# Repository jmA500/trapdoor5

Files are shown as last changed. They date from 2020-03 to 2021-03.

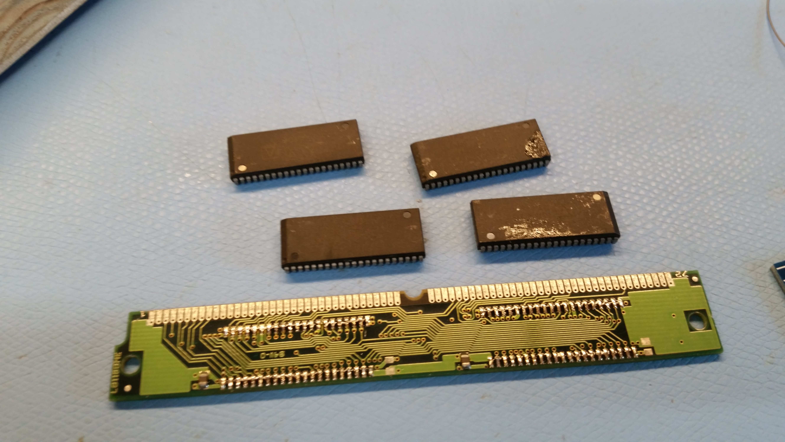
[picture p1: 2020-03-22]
doc/ps2-desoldered.jpg

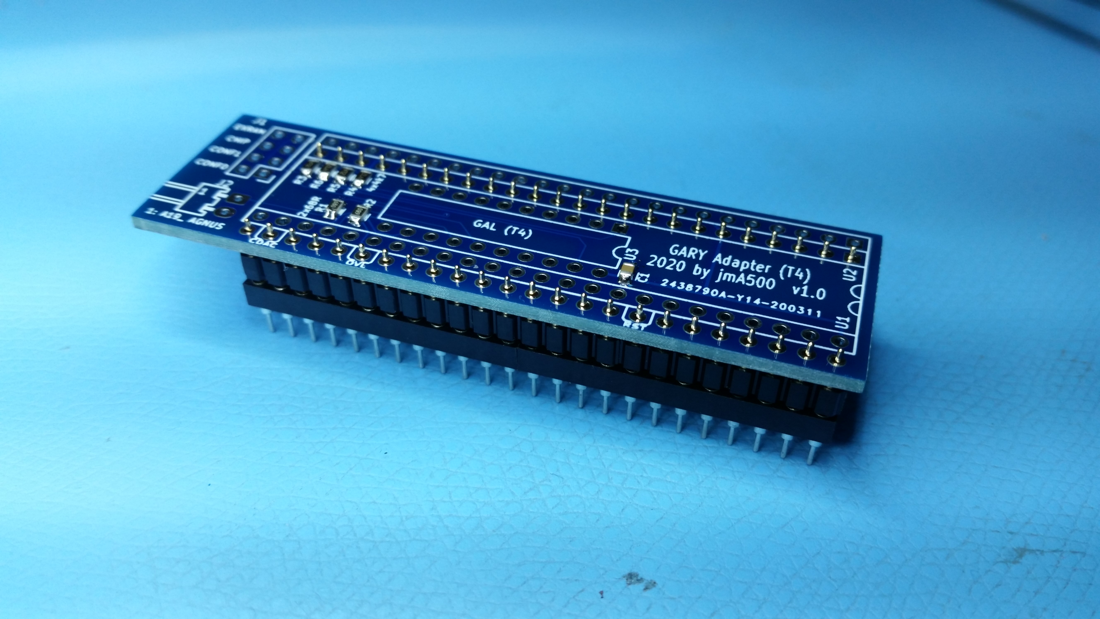
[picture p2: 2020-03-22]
doc/solder-pins.jpg

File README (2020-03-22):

This repository contains all the files to construct a Trapddor
expansion for the Amiga 500. There are some variants available. For
more information see the project website:

     https://www.jm27.de/for-commodore-amiga-500-1-8-mb-2mb-trapdoor-memory-expansion/

One variant uses a universal GARY Adapter (T3), the second one a
spcialized GARY adapter (T4). The T3 variant has as a main benefit
that the GARY adapter can be used with other original memory expansion
boards using a 74'139 to multiplex the CAS lines. The T4 version's
main feature is that there is no exra connection needed between the
GARY adapter and the Trapdoor board. 

Directories:

- doc: some documentation, needs to be extended

- pcb-trapdoor: kicad files for the pcb for the trapdoor assembly,
  both variants
- gal-trapdoor: Source and JED files for the GAL used on the trapdoor board
  CBR5SEL is needed for the T3 variant of the GARY adapter,
  CBR5EX is for the T4 variant
-pcb-gary-sel: the T3 GARY adater, kicad files
-pcb-gary-ext: the T4 GARY adapter, kicad files

- gal-gary: the corresponding GAL files
  GARY-T3: for the T3 variant
  GARY-T4: for the T4 variant

The PLD files can be compiled with WinCUPL available from Microchip. I
would be grateful fo a suggestion of a free alternative.

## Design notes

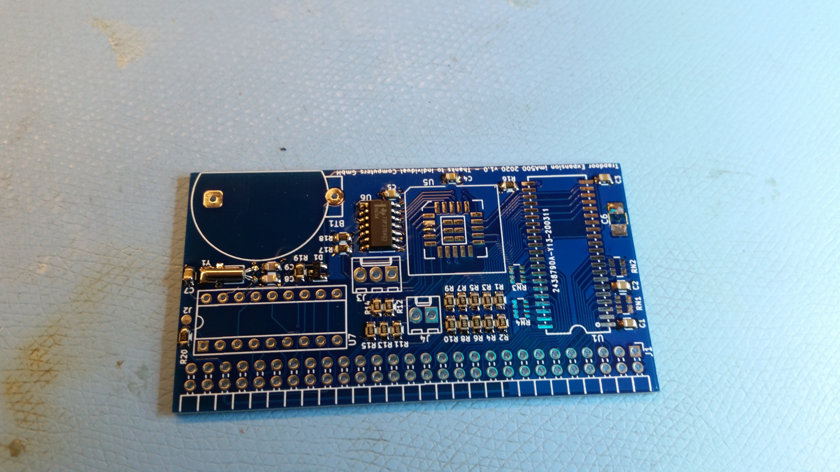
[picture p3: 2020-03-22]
doc/pcb-trapdoor.jpg

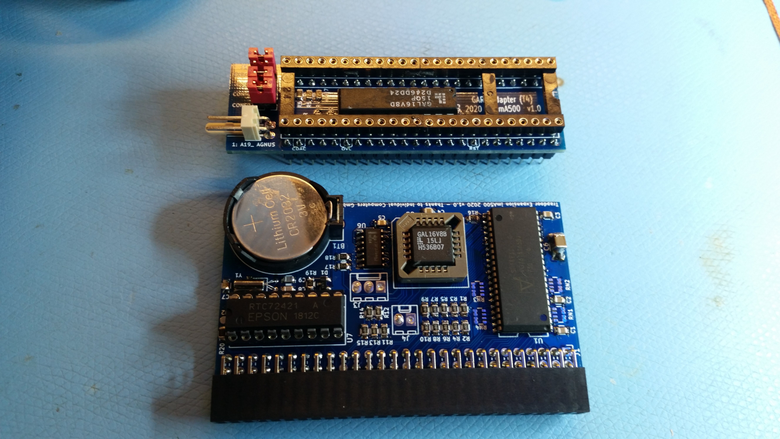
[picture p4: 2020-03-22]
doc/finished.jpg

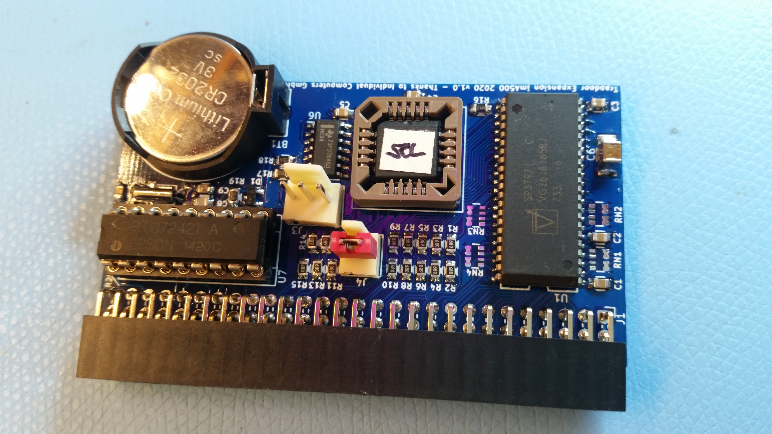
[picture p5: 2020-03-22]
doc/trapdoor-fertig.jpg

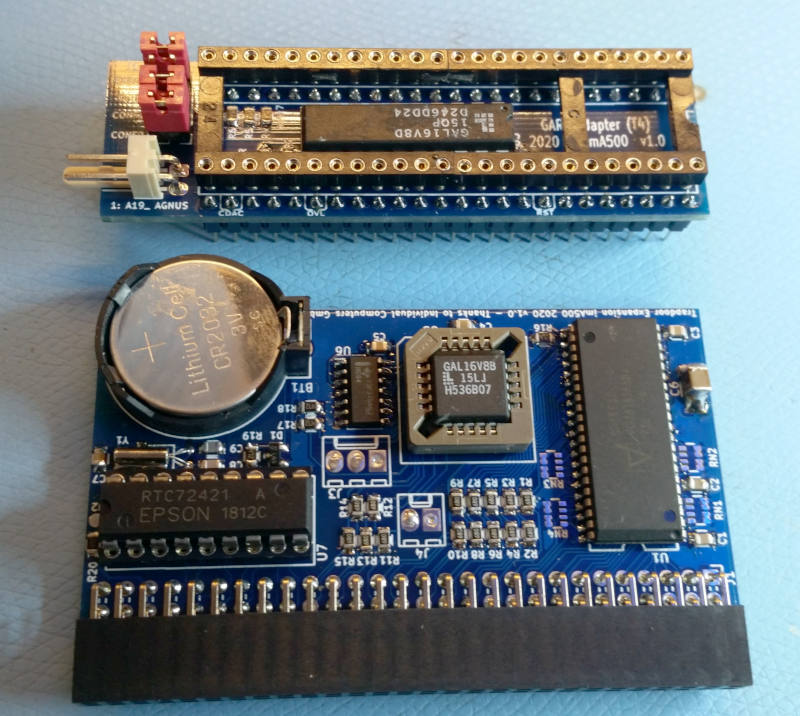
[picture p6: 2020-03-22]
doc/finished-small.jpg

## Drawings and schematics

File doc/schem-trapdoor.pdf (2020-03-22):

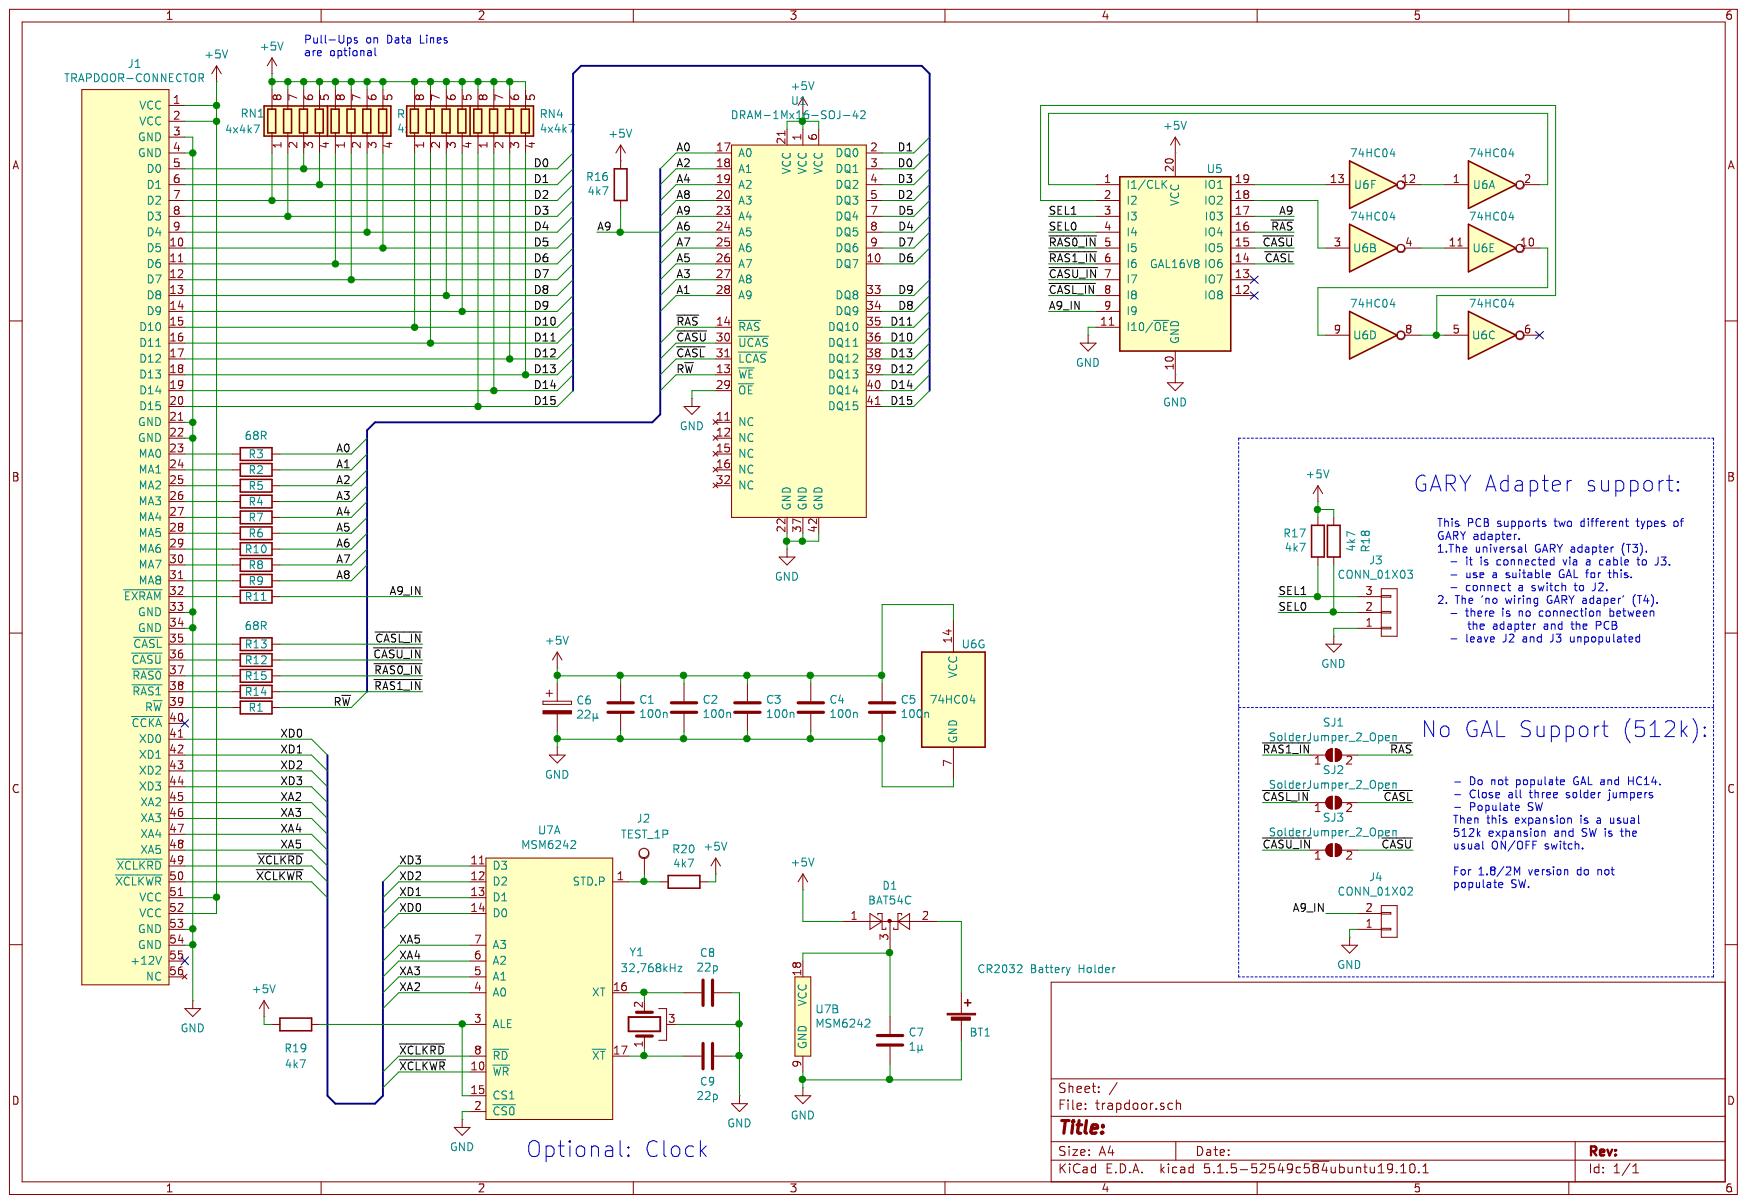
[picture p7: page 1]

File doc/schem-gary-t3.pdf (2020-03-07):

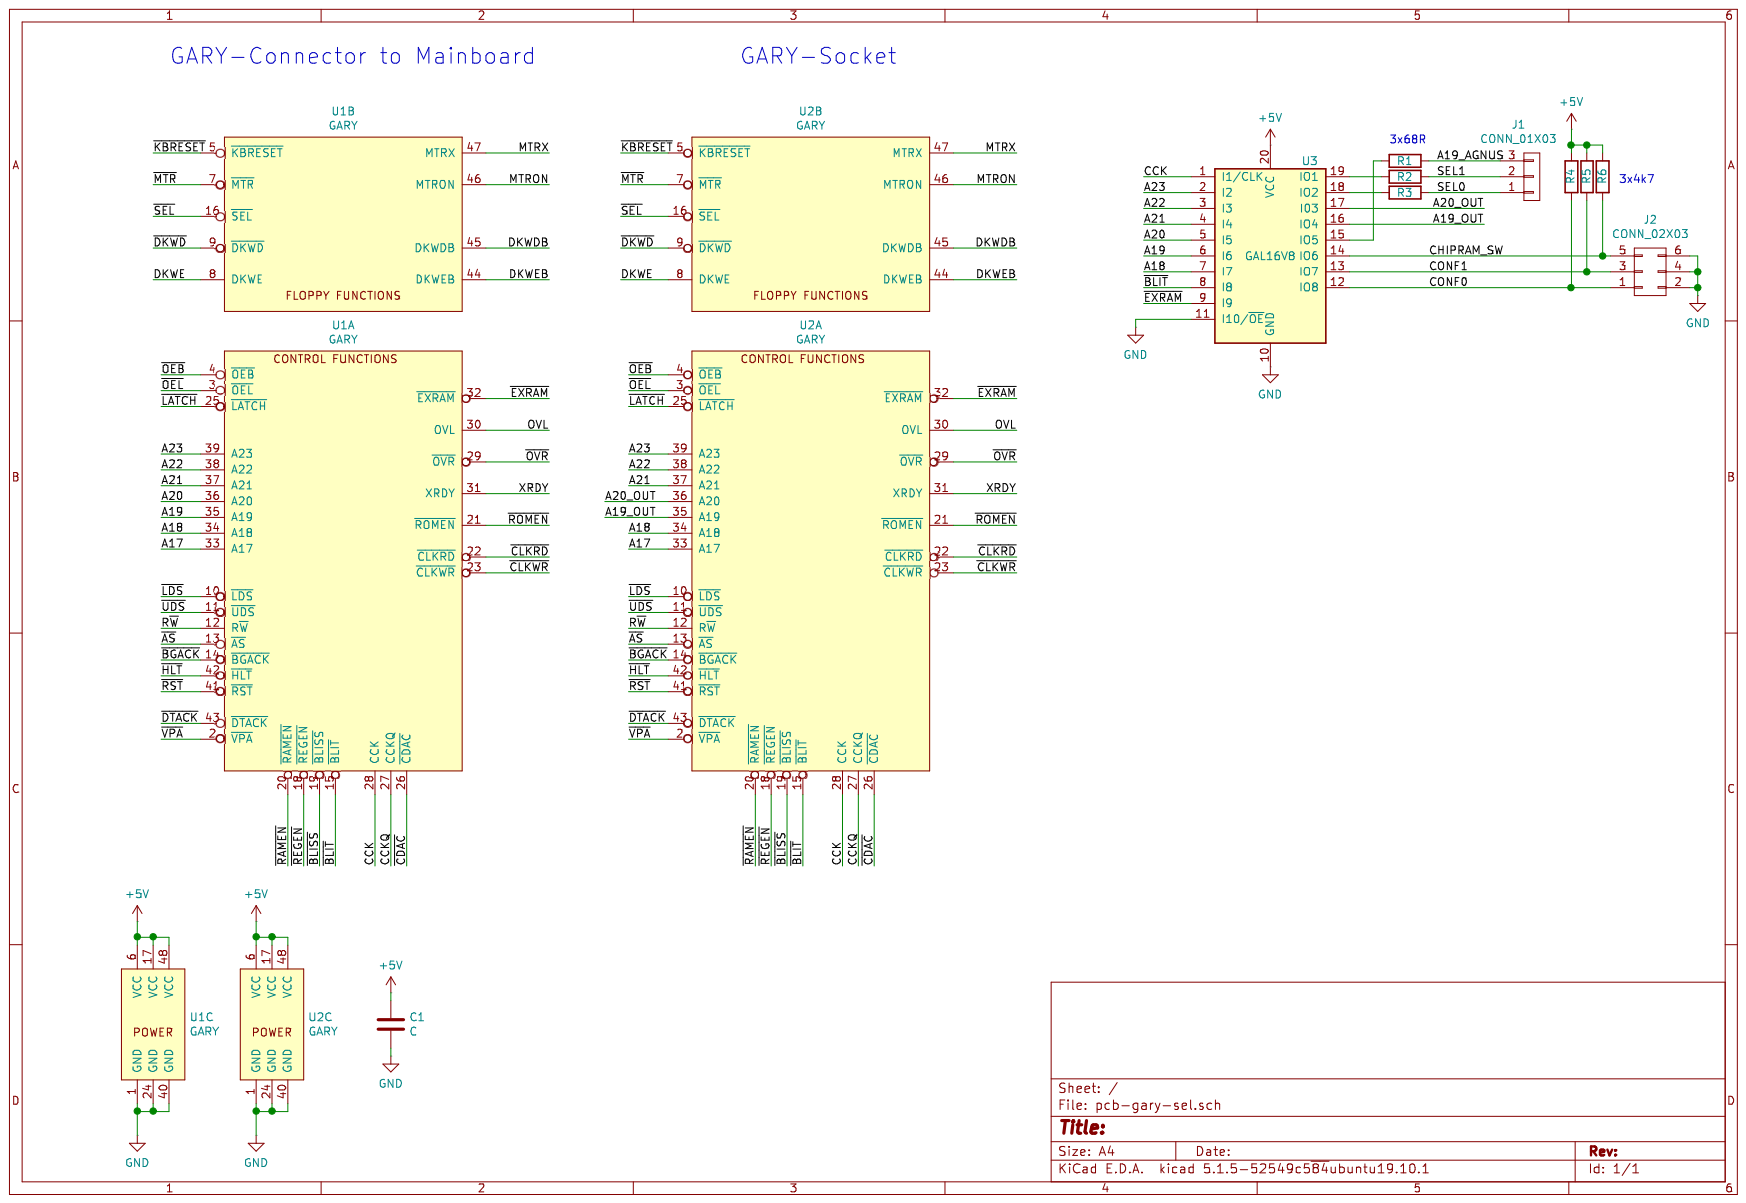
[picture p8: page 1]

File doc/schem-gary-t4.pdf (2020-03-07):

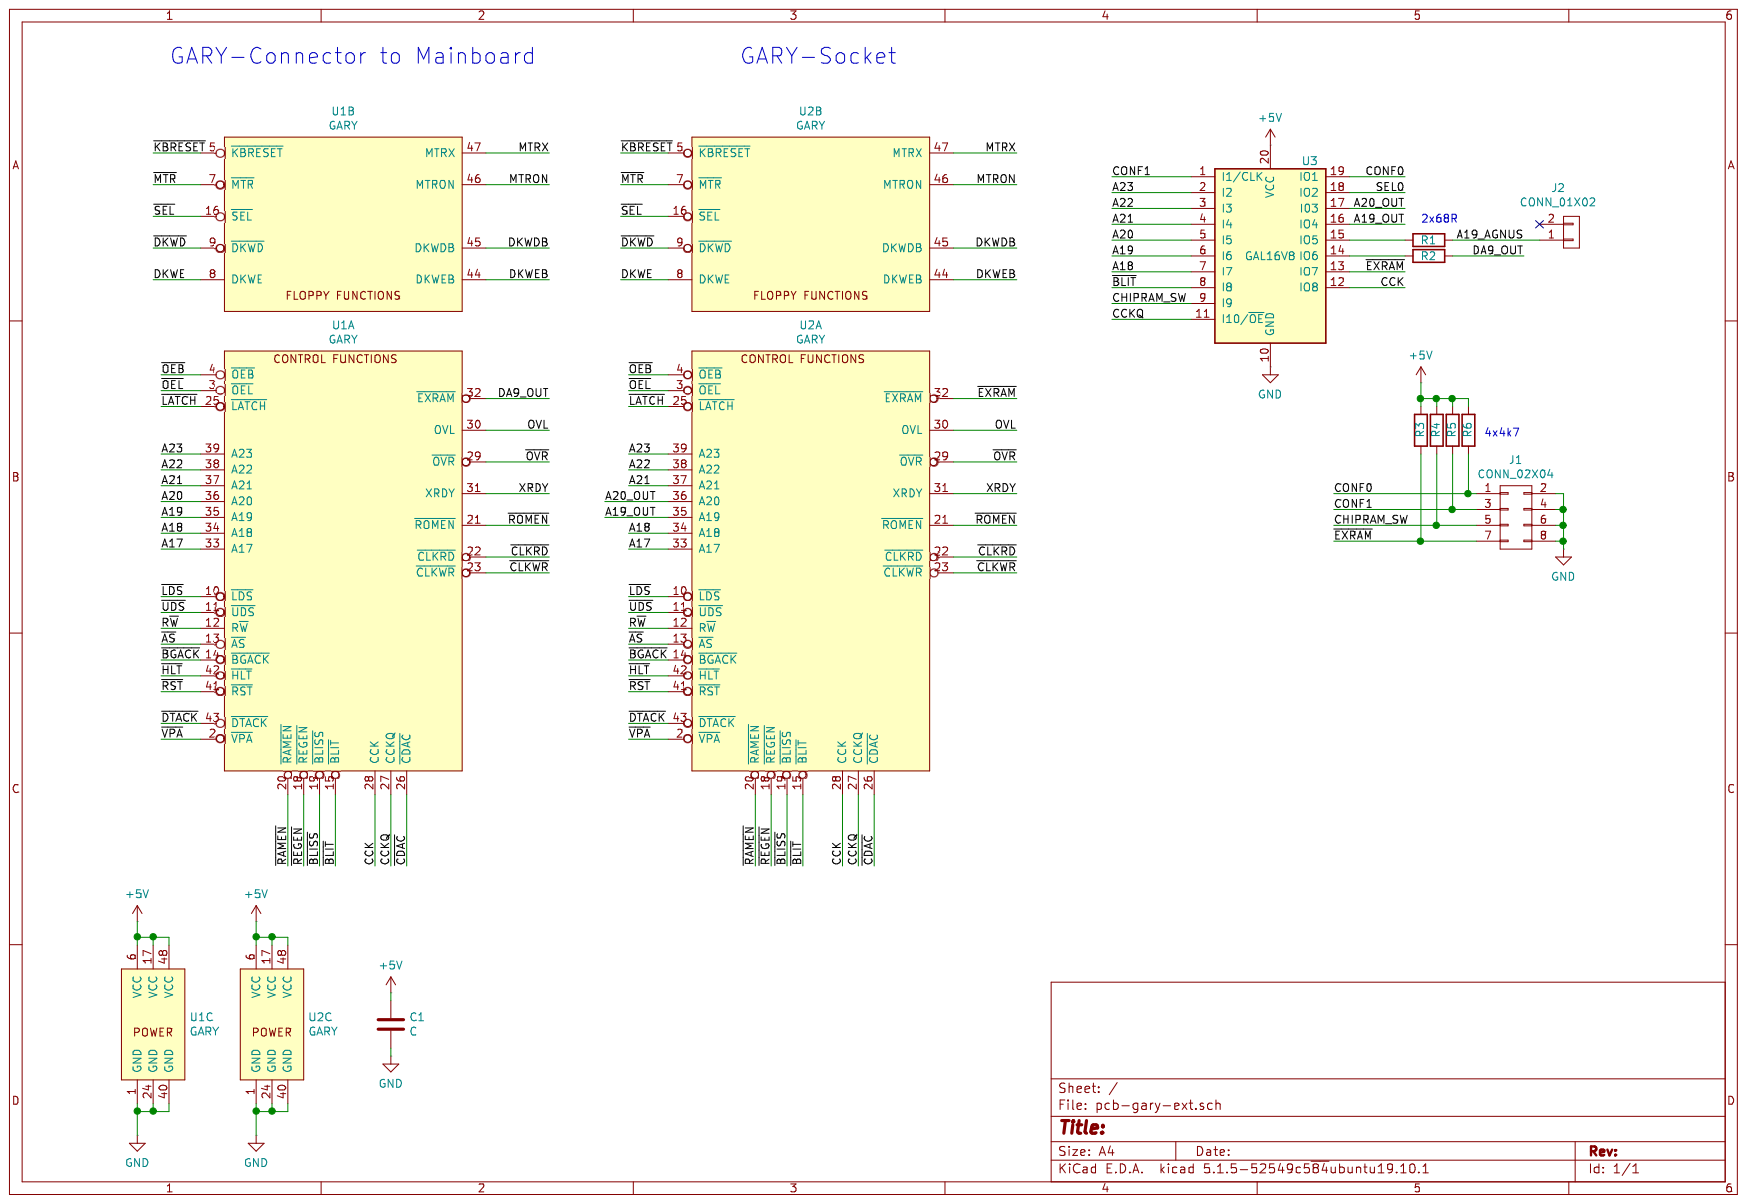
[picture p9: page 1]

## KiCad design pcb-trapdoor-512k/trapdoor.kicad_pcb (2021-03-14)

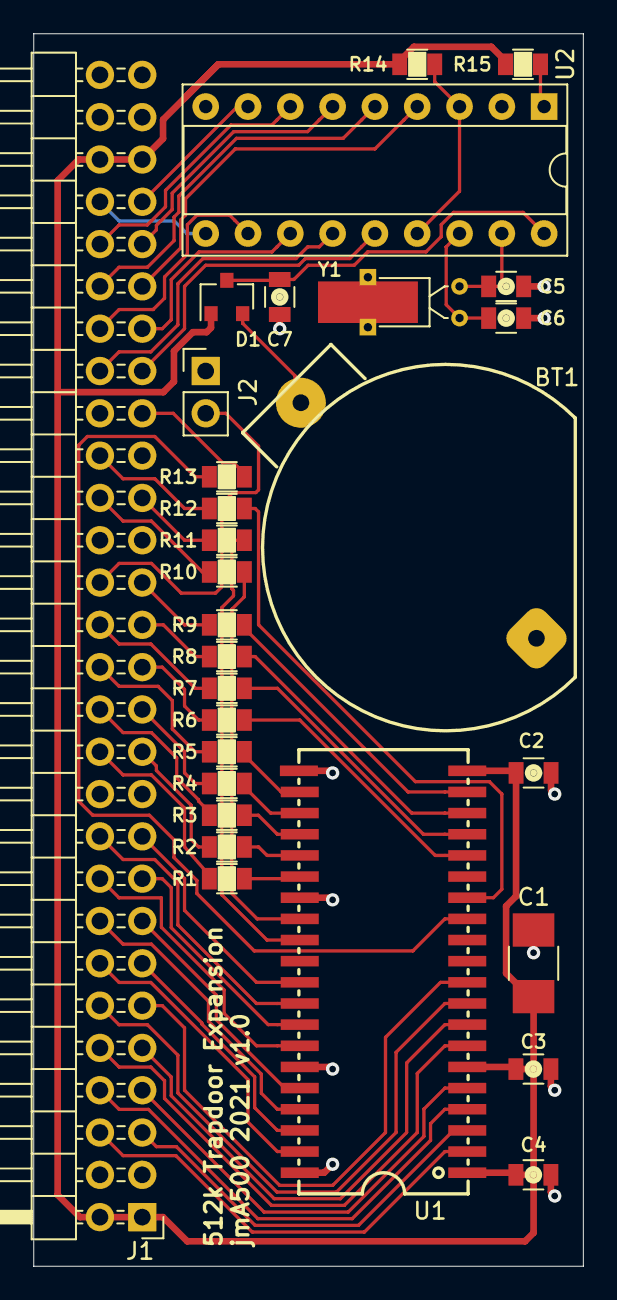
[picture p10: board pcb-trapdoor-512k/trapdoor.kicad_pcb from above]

Board: 2 copper layers, 33.0 x 74.0 mm, 29 parts (0 on the bottom side), 61 nets.

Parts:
BT1: CR2032 Battery Holder; BAT-CR2023-45
C1: 22µ; C_1210_HandSoldering
C2, C3, C4: 100n; C_0805
C5, C6: 22p; C_0805
C7: 1µ; C_0805
D1: BAT54C; SOT-23
J1: TRAPDOOR-CONNECTOR; Pin_Header_Angled_2x28_Pitch2.54mm
J2: CONN_01X02; Pin_Header_Straight_1x02_Pitch2.54mm
R1, R2, R3, R4, R5, R6, R7, R8, R9, R10, R11, R12, R13: 68R; R_0805
R14, R15: 4k7; R_0805
U1: DRAM-256kx16-SOJ; SOJ-40
U2: MSM6242; DIP-18_W7.62mm_Socket
Y1: 32,768kHz; Crystal_DS26_d2.0mm_l6.0mm_Horizontal_1EP_style2

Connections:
+5V: C1.1, C2.2, C3.2, C4.2, D1.1, J1.1, J1.2, J1.51, J1.52, R14.2, R15.1, U1.1, U1.6, U1.20
/A0: R2.1, U1.25
/A1: R1.1, U1.26
/A2: R4.1, U1.23
/A3: R3.1, U1.24
/A4: R6.1, U1.16
/A5: R5.1, U1.22
/A6: R8.1, U1.18
/A7: R7.1, U1.17
/A8: R9.1, U1.19
/D0: J1.5, U1.3
/D1: J1.6, U1.2
/D2: J1.7, U1.5
/D3: J1.8, U1.4
/D4: J1.9, U1.8
/D5: J1.10, U1.7
/D6: J1.11, U1.10
/D7: J1.12, U1.9
/D8: J1.13, U1.38
/D9: J1.14, U1.39
/D10: J1.15, U1.36
/D11: J1.16, U1.37
/D12: J1.17, U1.33
/D13: J1.18, U1.34
/D14: J1.19, U1.31
/D15: J1.20, U1.32
/R~W: R13.1, U1.13
/XA2: J1.45, U2.4
/XA3: J1.46, U2.5
/XA4: J1.47, U2.6
/XA5: J1.48, U2.7
/XD0: J1.41, U2.14
/XD1: J1.42, U2.13
/XD2: J1.43, U2.12
/XD3: J1.44, U2.11
/~CASL: R11.1, U1.29
/~CASU: R10.1, U1.28
/~EXRAM: J1.32, J2.2
/~RAS: R12.1, U1.14
/~XCLKRD: J1.49, U2.8
/~XCLKWR: J1.50, U2.10
GND: BT1.2, C1.2, C2.1, C3.1, C4.1, C5.1, C6.1, C7.1, J1.3, J1.4, J1.21, J1.22, J1.33, J1.34, J1.53, J1.54, J2.1, U1.21, U1.27, U1.35, U1.40, U2.2, U2.9, Y1.3
unnamed: BT1.1, D1.2
unnamed: C5.2, U2.17, Y1.1
unnamed: C6.2, U2.16, Y1.2
unnamed: C7.2, D1.3, U2.18
unnamed: J1.23, R2.2
unnamed: J1.24, R1.2
unnamed: J1.25, R4.2
unnamed: J1.26, R3.2
unnamed: J1.27, R6.2
unnamed: J1.28, R5.2
unnamed: J1.29, R8.2
unnamed: J1.30, R7.2
unnamed: J1.31, R9.2
unnamed: J1.35, R11.2
unnamed: J1.36, R10.2
unnamed: J1.38, R12.2
unnamed: J1.39, R13.2
unnamed: R14.1, U2.3, U2.15
unnamed: R15.2, U2.1

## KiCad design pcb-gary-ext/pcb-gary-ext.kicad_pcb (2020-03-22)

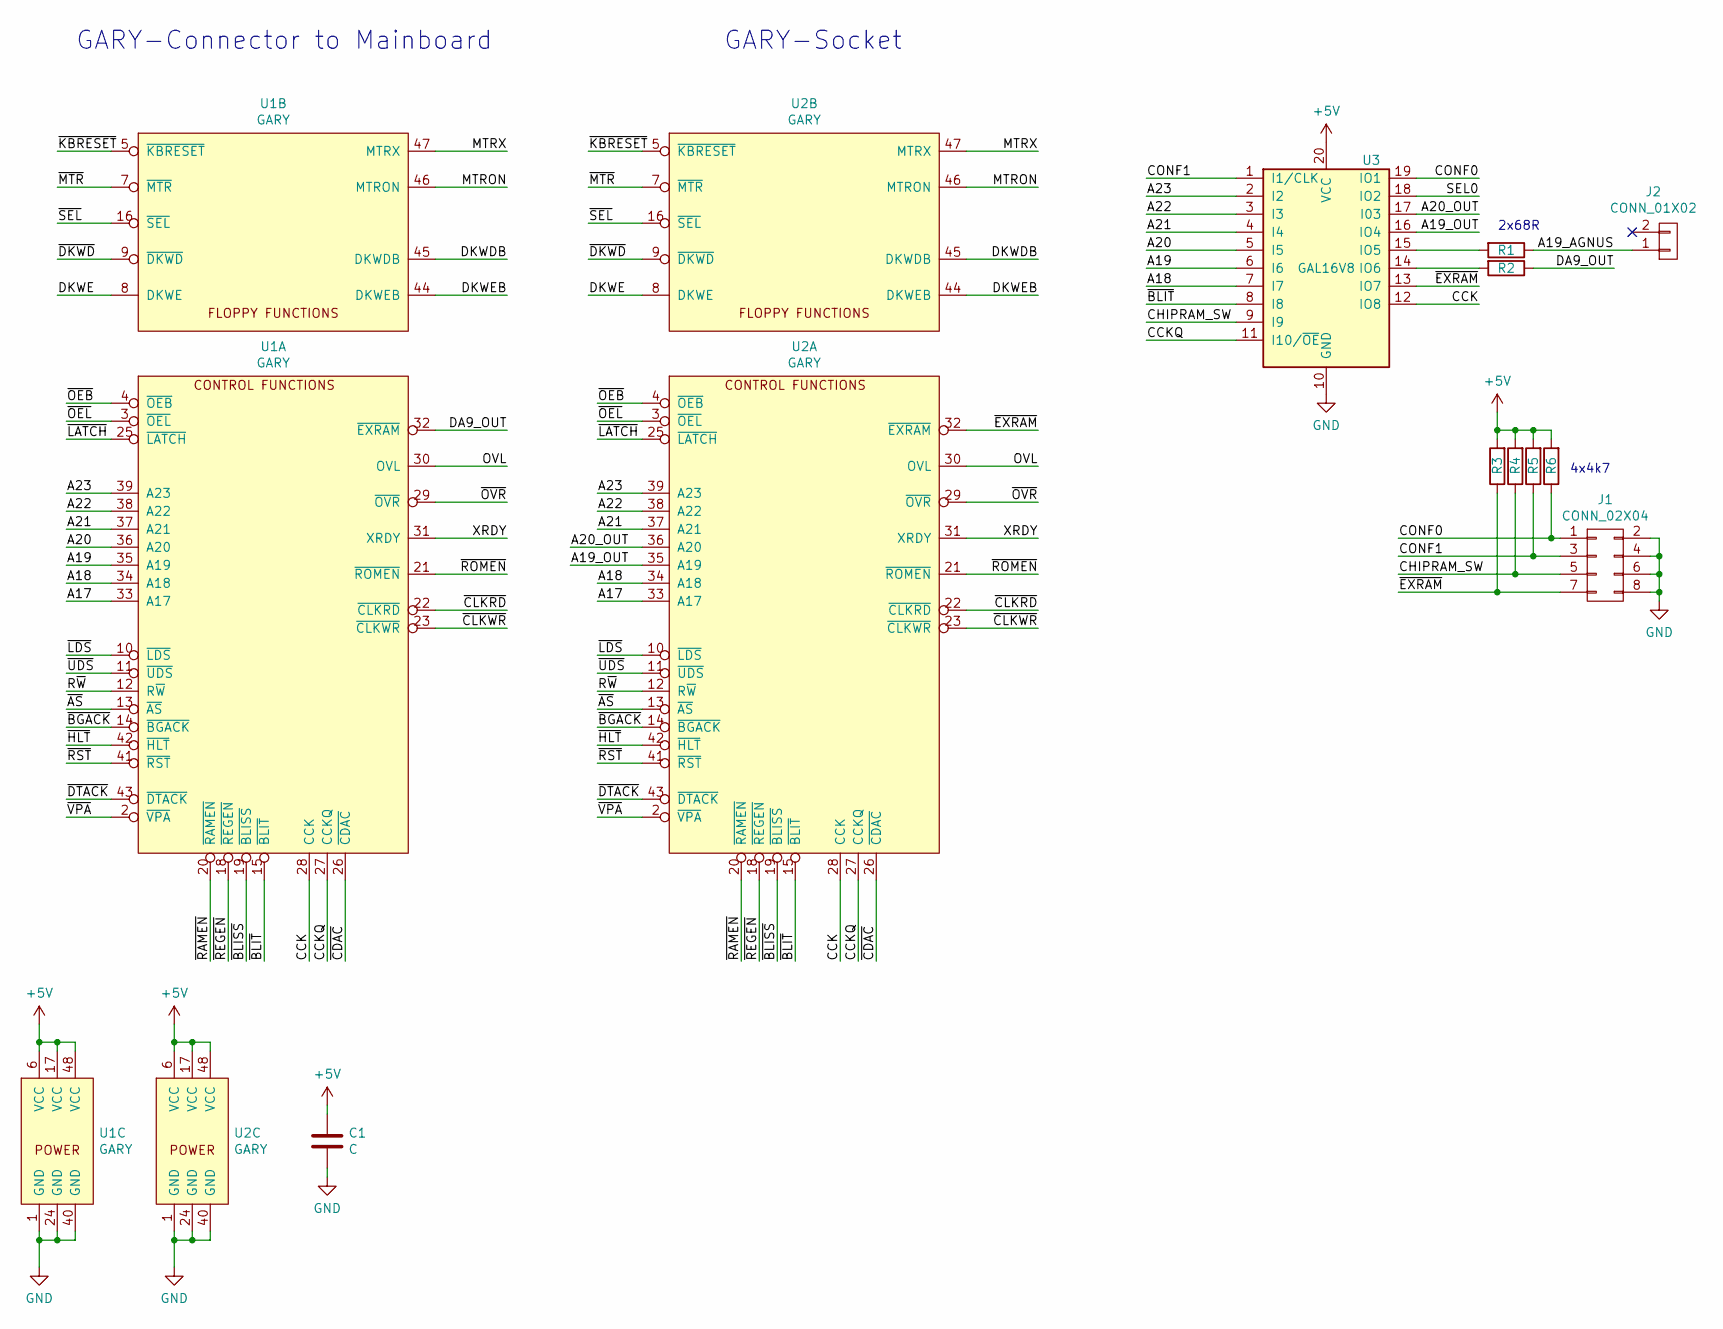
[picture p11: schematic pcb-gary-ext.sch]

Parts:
C1: C; C_0805
J1: CONN_02X04; Pin_Header_Straight_2x04_Pitch2.54mm
J2: CONN_01X02; MOLEX-KK-Angled-2
R1, R2: 68R; R_0805
R3, R4, R5, R6: 4k7; R_0805
U1, U2: GARY
U3: GAL16V8; DIP-20_W7.62mm

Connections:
+5V: C1.1, R3.2, R4.2, R5.2, R6.2, U1.6 (VCC), U1.17 (VCC), U1.48 (VCC), U2.6 (VCC), U2.17 (VCC), U2.48 (VCC), U3.20 (VCC)
/A17: U1.33 (A17), U2.33 (A17)
/A18: U1.34 (A18), U2.34 (A18), U3.7 (I7)
/A19: U1.35 (A19), U3.6 (I6)
/A19_AGNUS: J2.1, R1.1
/A19_OUT: U2.35 (A19), U3.16 (IO4)
/A20: U1.36 (A20), U3.5 (I5)
/A20_OUT: U2.36 (A20), U3.17 (I03)
/A21: U1.37 (A21), U2.37 (A21), U3.4 (I4)
/A22: U1.38 (A22), U2.38 (A22), U3.3 (I3)
/A23: U1.39 (A23), U2.39 (A23), U3.2 (I2)
/CCK: U1.28 (CCK), U2.28 (CCK), U3.12 (IO8)
/CCKQ: U1.27 (CCKQ), U2.27 (CCKQ), U3.11 (I10/~OE~)
/CHIPRAM_SW: J1.5, R4.1, U3.9 (I9)
/CONF0: J1.1, R6.1, U3.19 (IO1)
/CONF1: J1.3, R5.1, U3.1 (I1/CLK)
/DA9_OUT: R2.1, U1.32 (~EXRAM)
/DKWDB: U1.45 (DKWDB), U2.45 (DKWDB)
/DKWE: U1.8 (DKWE), U2.8 (DKWE)
/DKWEB: U1.44 (DKWEB), U2.44 (DKWEB)
/MTRON: U1.46 (MTRON), U2.46 (MTRON)
/MTRX: U1.47 (MTRX), U2.47 (MTRX)
/OVL: U1.30 (OVL), U2.30 (OVL)
/R~W: U1.12 (R~W), U2.12 (R~W)
/XRDY: U1.31 (XRDY), U2.31 (XRDY)
/~AS: U1.13 (~AS), U2.13 (~AS)
/~BGACK: U1.14 (~BGACK), U2.14 (~BGACK)
/~BLISS: U1.19 (~BLISS), U2.19 (~BLISS)
/~BLIT: U1.15 (~BLIT), U2.15 (~BLIT), U3.8 (I8)
/~CDAC: U1.26 (~CDAC), U2.26 (~CDAC)
/~CLKRD: U1.22 (~CLKRD), U2.22 (~CLKRD)
/~CLKWR: U1.23 (~CLKWR), U2.23 (~CLKWR)
/~DKWD: U1.9 (~DKWD), U2.9 (~DKWD)
/~DTACK: U1.43 (~DTACK), U2.43 (~DTACK)
/~EXRAM: J1.7, R3.1, U2.32 (~EXRAM), U3.13 (IO7)
/~HLT: U1.42 (~HLT), U2.42 (~HLT)
/~KBRESET: U1.5 (~KBRESET), U2.5 (~KBRESET)
/~LATCH: U1.25 (~LATCH), U2.25 (~LATCH)
/~LDS: U1.10 (~LDS), U2.10 (~LDS)
/~MTR: U1.7 (~MTR), U2.7 (~MTR)
/~OEB: U1.4 (~OEB), U2.4 (~OEB)
/~OEL: U1.3 (~OEL), U2.3 (~OEL)
/~OVR: U1.29 (~OVR), U2.29 (~OVR)
/~RAMEN: U1.20 (~RAMEN), U2.20 (~RAMEN)
/~REGEN: U1.18 (~REGEN), U2.18 (~REGEN)
/~ROMEN: U1.21 (~ROMEN), U2.21 (~ROMEN)
/~RST: U1.41 (~RST), U2.41 (~RST)
/~SEL: U1.16 (~SEL), U2.16 (~SEL)
/~UDS: U1.11 (~UDS), U2.11 (~UDS)
/~VPA: U1.2 (~VPA), U2.2 (~VPA)
GND: C1.2, J1.2, J1.4, J1.6, J1.8, U1.1 (GND), U1.24 (GND), U1.40 (GND), U2.1 (GND), U2.24 (GND), U2.40 (GND), U3.10 (GND)
unnamed: R1.2, U3.15 (IO5)
unnamed: R2.2, U3.14 (IO6)

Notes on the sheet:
GARY-Connector to Mainboard
GARY-Socket
2x68R
4x4k7

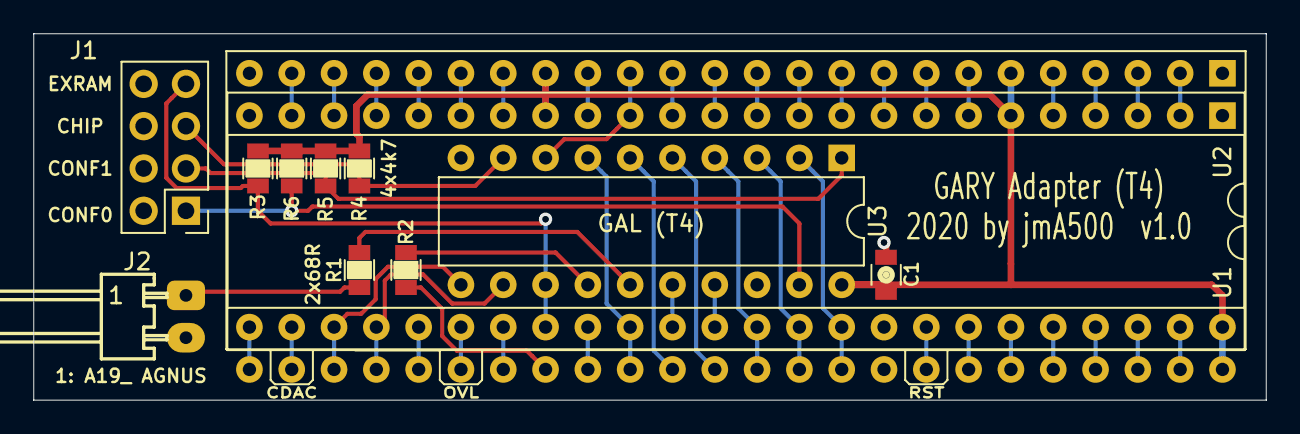
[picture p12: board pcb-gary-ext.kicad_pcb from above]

Board: 2 copper layers, 74.0 x 22.0 mm, 12 parts (0 on the bottom side), 53 nets.

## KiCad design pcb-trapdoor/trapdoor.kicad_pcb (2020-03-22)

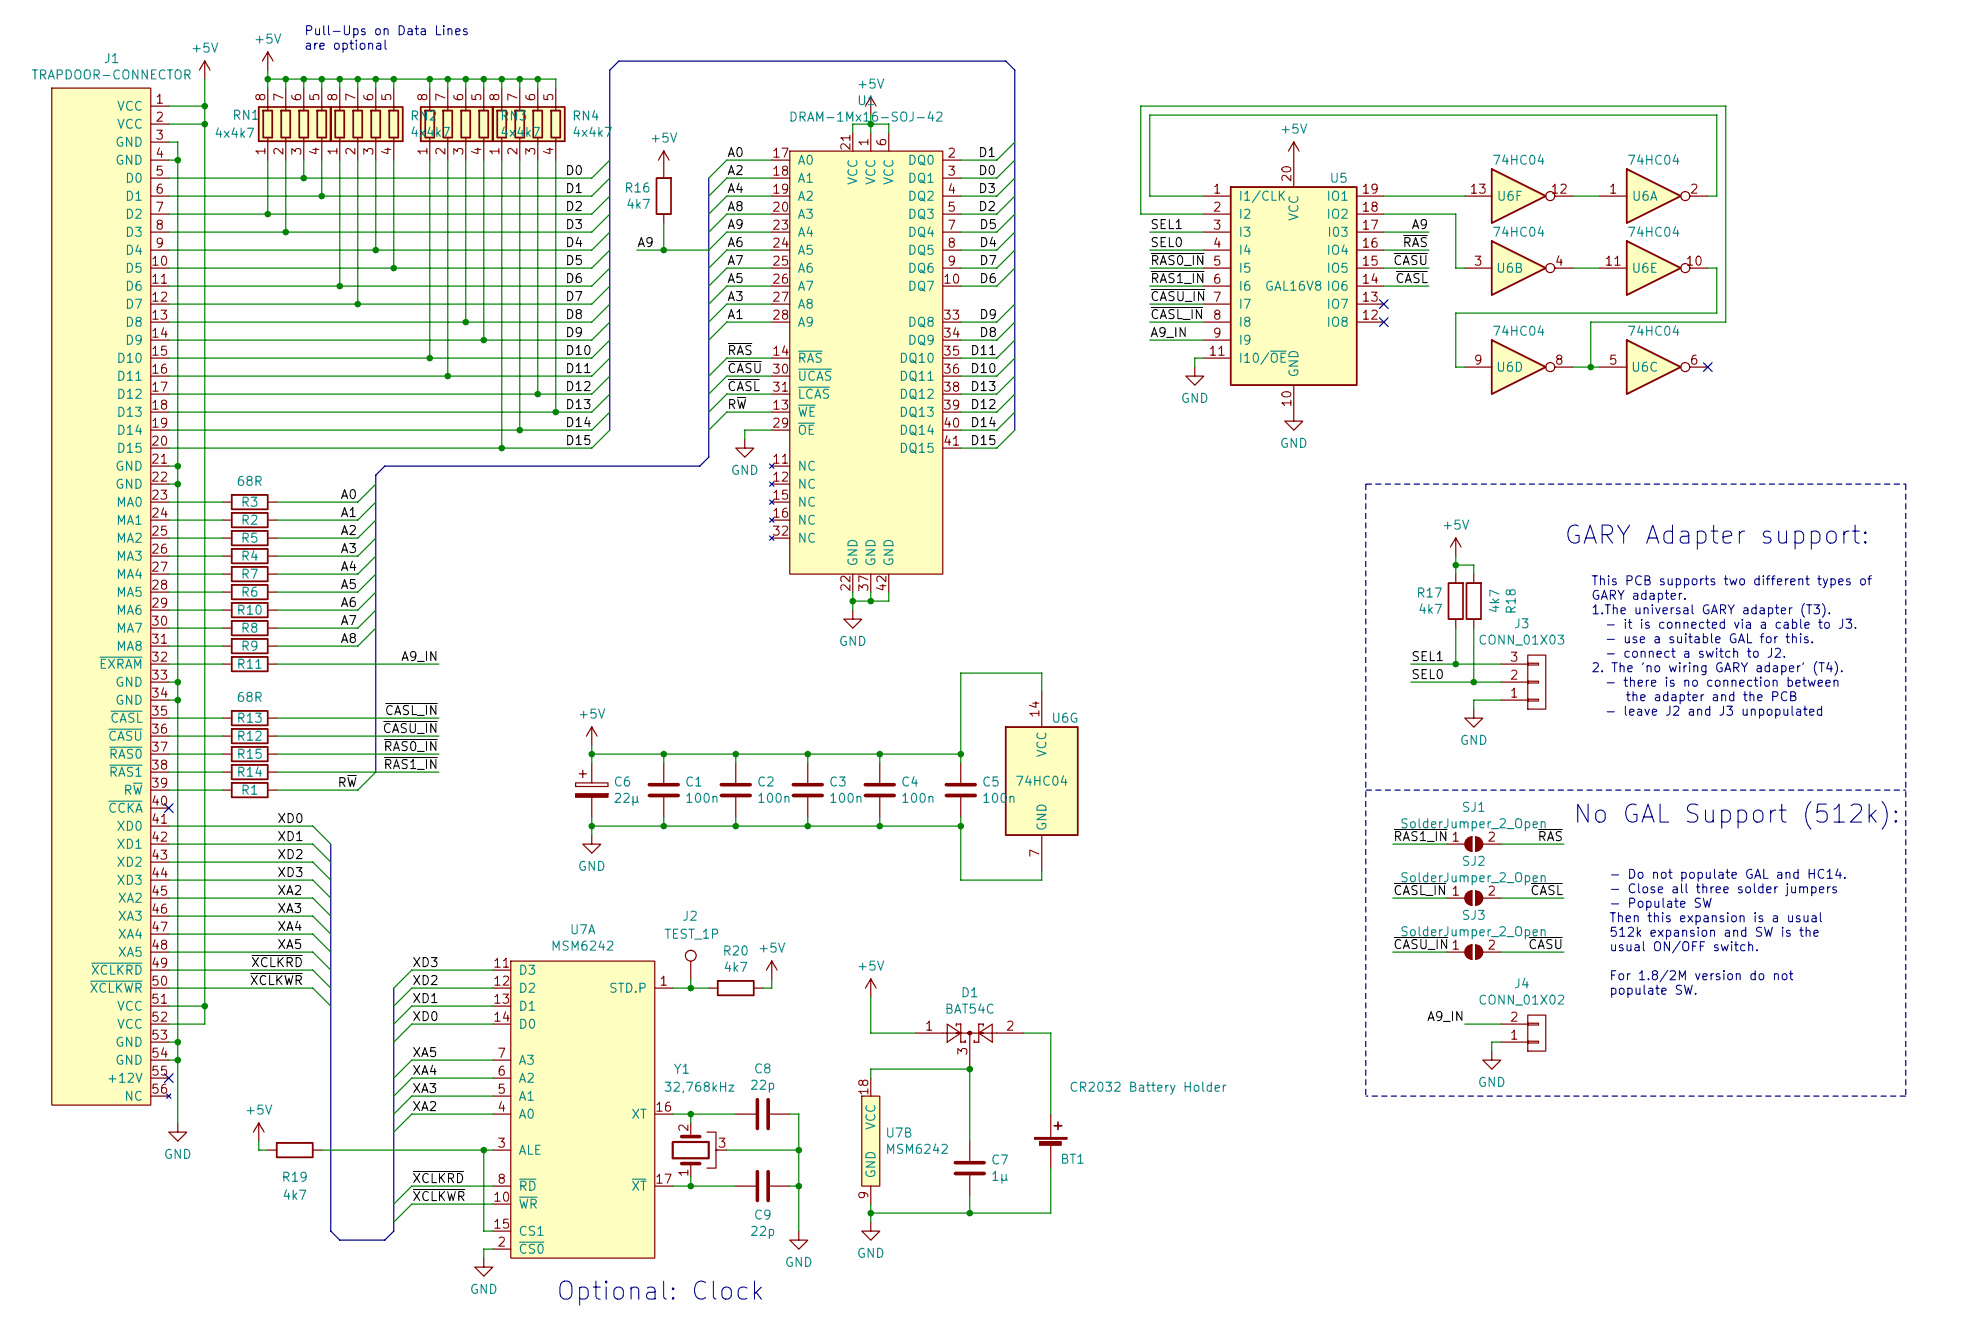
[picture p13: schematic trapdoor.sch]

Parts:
BT1: CR2032 Battery Holder; BAT-CR2032
C1, C2, C3, C4, C5: 100n; C_0805
C6: 22µ; C_1210_HandSoldering
C7: 1µ; C_0805
C8, C9: 22p; C_0805
D1: BAT54C; SOT-23
J1: TRAPDOOR-CONNECTOR; Pin_Header_Angled_2x28_Pitch2.54mm
J2: TEST_1P; Measurement_Point_Round-SMD-Pad_Small
J3: CONN_01X03; Molex_KK-6410-03_03x2.54mm_Straight
J4: CONN_01X02; Molex_KK-6410-02_02x2.54mm_Straight
R1, R2, R3, R4, R5, R6, R7, R8, R9, R10, R11, R12, R13, R14, R15: 68R; R_0805
R16, R17, R18, R19, R20: 4k7; R_0805
RN1, RN2, RN3, RN4: 4x4k7; R_Array_4x0603
SJ1, SJ2, SJ3: SolderJumper_2_Open; SMD-Jumper
U1: DRAM-1Mx16-SOJ-42; SOJ-42
U5: GAL16V8; PLCC-20_SMD-Socket
U6: 74HC04; SOIC-14_3.9x8.7mm_Pitch1.27mm
U7: MSM6242; DIP-18_W7.62mm_Socket
Y1: 32,768kHz; Crystal_DS26_d2.0mm_l6.0mm_Horizontal_1EP_style2

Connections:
+5V: C1.2, C2.2, C3.2, C4.2, C5.2, C6.1, D1.1, J1.1 (VCC), J1.2 (VCC), J1.51 (VCC), J1.52 (VCC), R16.2, R17.2, R18.2, R19.2, R20.1, RN1.5 (R4.2), RN1.6 (R3.2), RN1.7 (R2.2), RN1.8 (R1.2), RN2.5 (R4.2), RN2.6 (R3.2), RN2.7 (R2.2), RN2.8 (R1.2), RN3.5 (R4.2), RN3.6 (R3.2), RN3.7 (R2.2), RN3.8 (R1.2), RN4.5 (R4.2), RN4.6 (R3.2), RN4.7 (R2.2), RN4.8 (R1.2), U1.1 (VCC), U1.6 (VCC), U1.21 (VCC), U5.20 (VCC), U6.14 (VCC)
/A0: R3.1, U1.17 (A0)
/A1: R2.1, U1.28 (A9)
/A2: R5.1, U1.18 (A1)
/A3: R4.1, U1.27 (A8)
/A4: R7.1, U1.19 (A2)
/A5: R6.1, U1.26 (A7)
/A6: R10.1, U1.24 (A5)
/A7: R8.1, U1.25 (A6)
/A8: R9.1, U1.20 (A3)
/A9: R16.1, U1.23 (A4), U5.17 (I03)
/A9_IN: J4.2, R11.1, U5.9 (I9)
/D0: J1.5 (D0), RN1.3 (R3.1), U1.3 (DQ1)
/D1: J1.6 (D1), RN1.4 (R4.1), U1.2 (DQ0)
/D2: J1.7 (D2), RN1.1 (R1.1), U1.5 (DQ3)
/D3: J1.8 (D3), RN1.2 (R2.1), U1.4 (DQ2)
/D4: J1.9 (D4), RN2.3 (R3.1), U1.8 (DQ5)
/D5: J1.10 (D5), RN2.4 (R4.1), U1.7 (DQ4)
/D6: J1.11 (D6), RN2.1 (R1.1), U1.10 (DQ7)
/D7: J1.12 (D7), RN2.2 (R2.1), U1.9 (DQ6)
/D8: J1.13 (D8), RN3.3 (R3.1), U1.34 (DQ9)
/D9: J1.14 (D9), RN3.4 (R4.1), U1.33 (DQ8)
/D10: J1.15 (D10), RN3.1 (R1.1), U1.36 (DQ11)
/D11: J1.16 (D11), RN3.2 (R2.1), U1.35 (DQ10)
/D12: J1.17 (D12), RN4.3 (R3.1), U1.39 (DQ13)
/D13: J1.18 (D13), RN4.4 (R4.1), U1.38 (DQ12)
/D14: J1.19 (D14), RN4.2 (R2.1), U1.40 (DQ14)
/D15: J1.20 (D15), RN4.1 (R1.1), U1.41 (DQ15)
/R~W: R1.1, U1.13 (~WE)
/SEL0: J3.2, R18.1, U5.4 (I4)
/SEL1: J3.3, R17.1, U5.3 (I3)
/XA2: J1.45 (XA2), U7.4 (A0)
/XA3: J1.46 (XA3), U7.5 (A1)
/XA4: J1.47 (XA4), U7.6 (A2)
/XA5: J1.48 (XA5), U7.7 (A3)
/XD0: J1.41 (XD0), U7.14 (D0)
/XD1: J1.42 (XD1), U7.13 (D1)
/XD2: J1.43 (XD2), U7.12 (D2)
/XD3: J1.44 (XD3), U7.11 (D3)
/~CASL: SJ2.2 (B), U1.31 (~LCAS), U5.14 (IO6)
/~CASL_IN: R13.1, SJ2.1 (A), U5.8 (I8)
/~CASU: SJ3.2 (B), U1.30 (~UCAS), U5.15 (IO5)
/~CASU_IN: R12.1, SJ3.1 (A), U5.7 (I7)
/~RAS: SJ1.2 (B), U1.14 (~RAS), U5.16 (IO4)
/~RAS0_IN: R15.1, U5.5 (I5)
/~RAS1_IN: R14.1, SJ1.1 (A), U5.6 (I6)
/~XCLKRD: J1.49 (~XCLKRD), U7.8 (~RD)
/~XCLKWR: J1.50 (~XCLKWR), U7.10 (~WR)
GND: BT1.2 (-), C1.1, C2.1, C3.1, C4.1, C5.1, C6.2, C7.1, C8.1, C9.1, J1.3 (GND), J1.4 (GND), J1.21 (GND), J1.22 (GND), J1.33 (GND), J1.34 (GND), J1.53 (GND), J1.54 (GND), J3.1, J4.1, U1.22 (GND), U1.29 (~OE), U1.37 (GND), U1.42 (GND), U5.10 (GND), U5.11 (I10/~OE~), U6.7 (GND), U7.2 (~CS0), U7.9 (GND), Y1.3
unnamed: BT1.1 (+), D1.2
unnamed: C7.2, D1.3, U7.18 (VCC)
unnamed: C8.2, U7.16 (XT), Y1.2
unnamed: C9.2, U7.17 (~XT), Y1.1
unnamed: J1.23 (MA0), R3.2
unnamed: J1.24 (MA1), R2.2
unnamed: J1.25 (MA2), R5.2
unnamed: J1.26 (MA3), R4.2
unnamed: J1.27 (MA4), R7.2
unnamed: J1.28 (MA5), R6.2
unnamed: J1.29 (MA6), R10.2
unnamed: J1.30 (MA7), R8.2
unnamed: J1.31 (MA8), R9.2
unnamed: J1.32 (~EXRAM), R11.2
unnamed: J1.35 (~CASL), R13.2
unnamed: J1.36 (~CASU), R12.2
unnamed: J1.37 (~RAS0), R15.2
unnamed: J1.38 (~RAS1), R14.2
unnamed: J1.39 (R~W), R1.2
unnamed: J2.1, R20.2, U7.1 (STD.P)
unnamed: R19.1, U7.3 (ALE), U7.15 (CS1)
unnamed: U5.1 (I1/CLK), U6.2
unnamed: U5.2 (I2), U6.5, U6.8
unnamed: U5.18 (IO2), U6.3
unnamed: U5.19 (IO1), U6.13
unnamed: U6.1, U6.12
unnamed: U6.9, U6.10
unnamed: U6.4, U6.11

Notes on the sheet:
Optional: Clock
Pull-Ups on Data Lines are optional
No GAL Support (512k):
- Do not populate GAL and HC14. - Close all three solder jumpers - Populate SW Then this expansion is a usual 512k expansion and SW is the usual ON/OFF switch. For 1.8/2M version do not populate SW.
GARY Adapter support:
This PCB supports two different types of GARY adapter. 1.The universal GARY adapter (T3). - it is connected via a cable to J3. - use a suitable GAL for this. - connect a switch to J2. 2. The 'no wiring GARY adaper' (T4). - there is no connection between the adapter and the PCB - leave J2 and J3 unp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

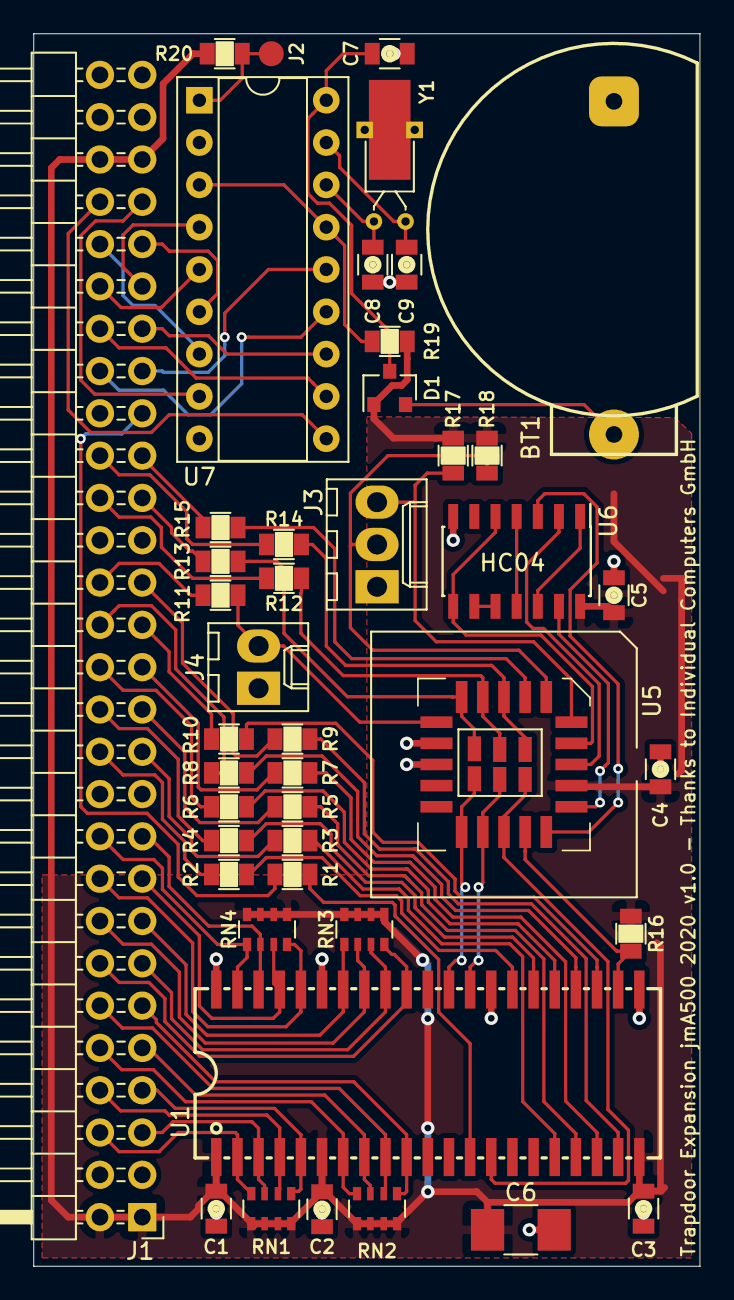
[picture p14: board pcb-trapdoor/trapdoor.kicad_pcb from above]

Board: 2 copper layers, 40.0 x 74.0 mm, 47 parts (0 on the bottom side), 77 nets.

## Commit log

2020-03-05 Trapdoor Platine fertig. Platine kann für beide Gary-Adapter konfiguriert werden. Dazu CPLD-Code für beide Versionen.
    [trapdoor.kicad_pcb, trapdoor.sch]
2020-03-06 PCBs hinzugefügt.
    [pcb-gary-ext.kicad_pcb, pcb-gary-ext.sch, pcb-gary-sel.kicad_pcb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]
2020-03-10 Update PCB für Trapdoor.
    [trapdoor.kicad_pcb, trapdoor.sch]
2020-03-22 Updated schmatic.
    [pcb-gary-ext.kicad_pcb, trapdoor.kicad_pcb, trapdoor.sch]
2020-03-22 Update Projektverzeichnis
    [trapdoor.sch]
2021-03-14 * Added PCB for 512k-Trapdoor expansion * Some repository cleanup
    [trapdoor.kicad_pcb, trapdoor.sch]
